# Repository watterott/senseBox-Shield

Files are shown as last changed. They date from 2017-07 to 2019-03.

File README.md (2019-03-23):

# senseBox-Shield
The senseBox-Shield is a plug-on module for Arduino to connect different sensor modules.

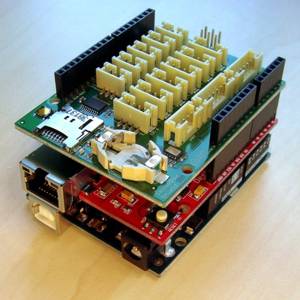
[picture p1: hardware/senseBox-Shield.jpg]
senseBox-Shield


* JST connectors for different sensors
* microSD socket (SPI) support SD and SDHC cards
* RV-8523 RTC (I2C Real-Time-Clock) with backup battery
* Open-Source
* **[Documentation on learn.watterott.com](https://learn.watterott.com)**

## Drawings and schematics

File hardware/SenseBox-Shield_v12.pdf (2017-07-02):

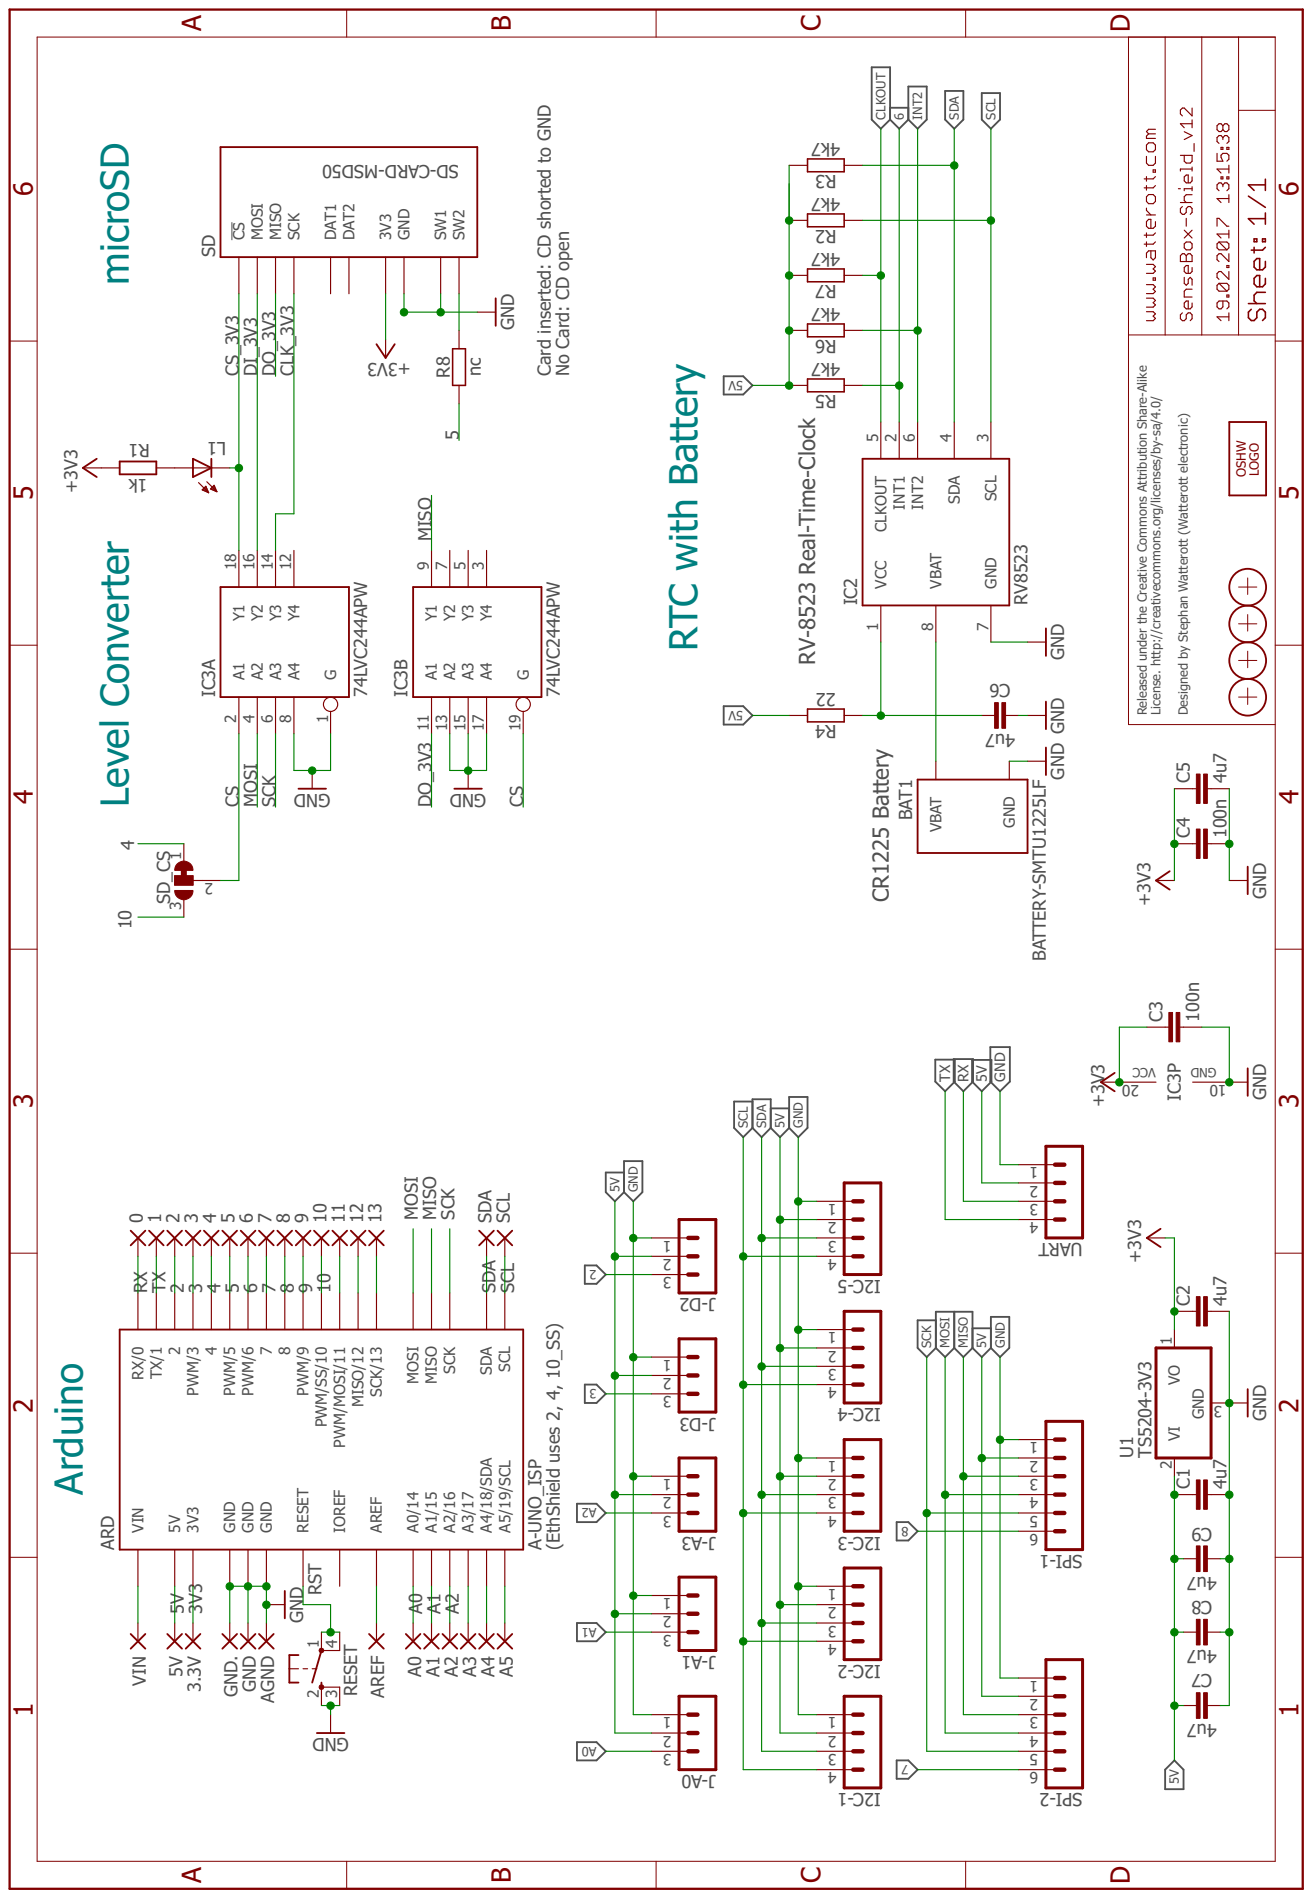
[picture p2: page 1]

Card inserted: CD shorted to GND

No Card: CD open

Released under the Creative Commons At ribution Share-Alike

License. http://creativecommons.org/licenses/by-sa/4.0/ Designed by Stephan Watterott (Watterott electronic)

RV-8523 Real-Time-Clock C

8 PWM/9 PWM/SS/10 PWM/MOSI/11 MISO/12 SCK/13 A1/15 A2/16 A3/17 A4/18/SDA

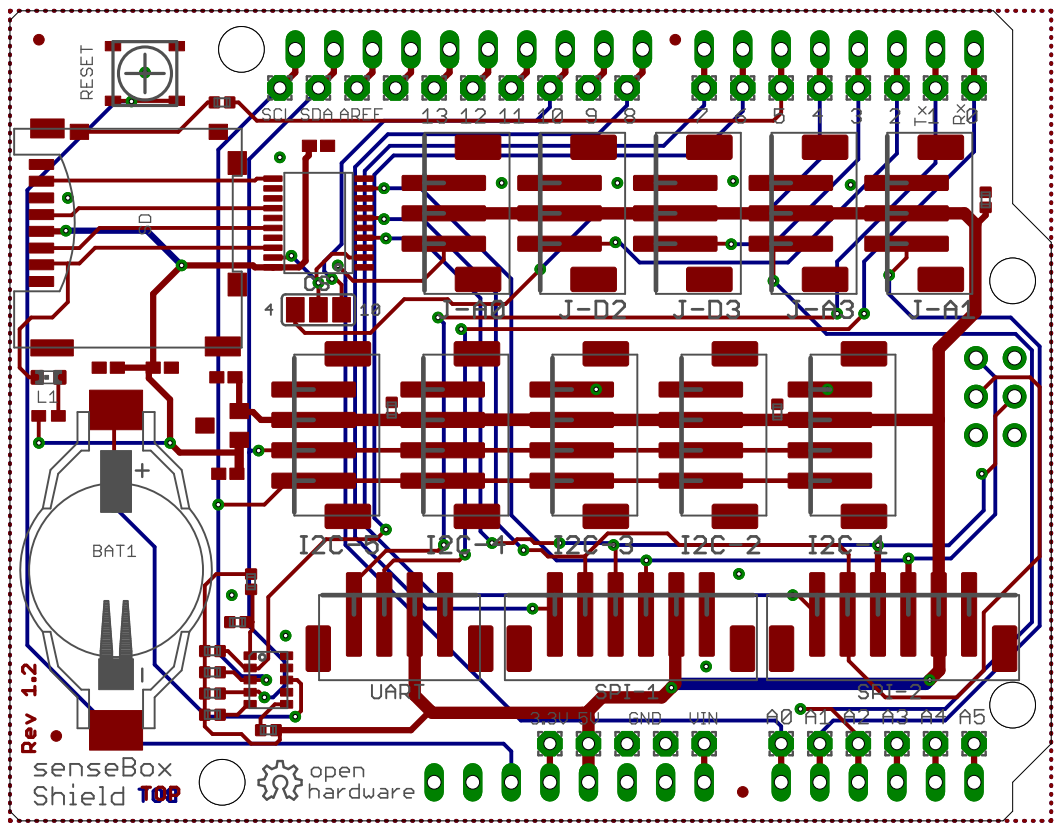
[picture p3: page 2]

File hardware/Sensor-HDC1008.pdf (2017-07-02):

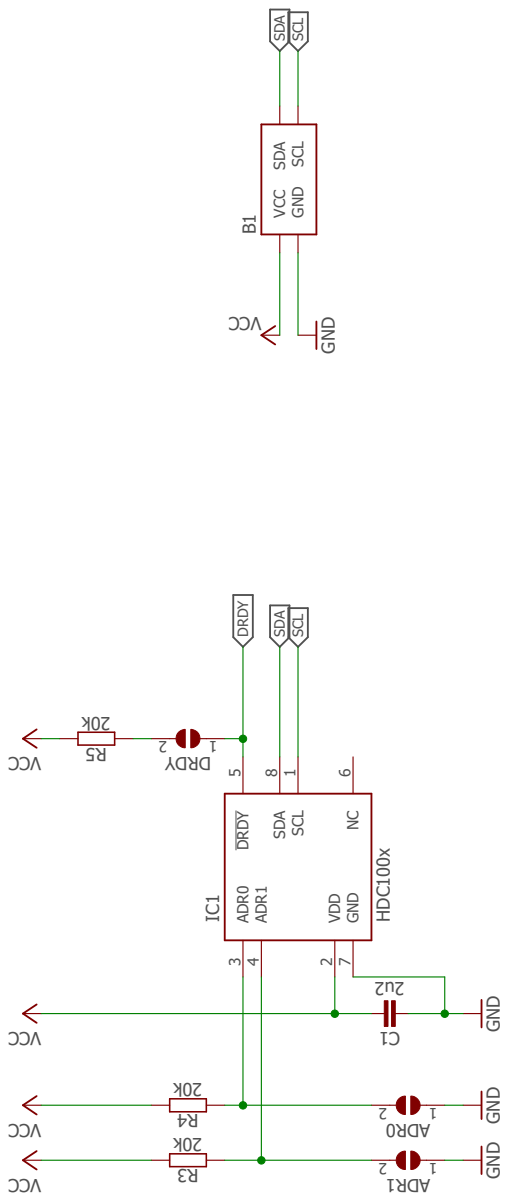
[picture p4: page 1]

CCV 2u2 GND k02 k02 CCV CCV k02 GND GND CCV GND CCV HDC100x Released under the Creative Commons At ribution Share-Alike License. http://creativecommons.org/licenses/by-sa/4.0/ Designed by Stephan Watterott (Watterott electronic) 1C 3R4R 5R 1RDA 2 1 0RDA 2 1 YDRD 2 1 SCL 1 VDD 2 ADR0 3 ADR1 4 SDA 8 GND 7 NC 6 DRDY 5 IC1 B1 SDA SCL VCC GND DRDY SDA SDA SCL SCL OSHW LOGO ABCD 1 2 3 4 5 6 ABCD 1 2 3 4 5 6

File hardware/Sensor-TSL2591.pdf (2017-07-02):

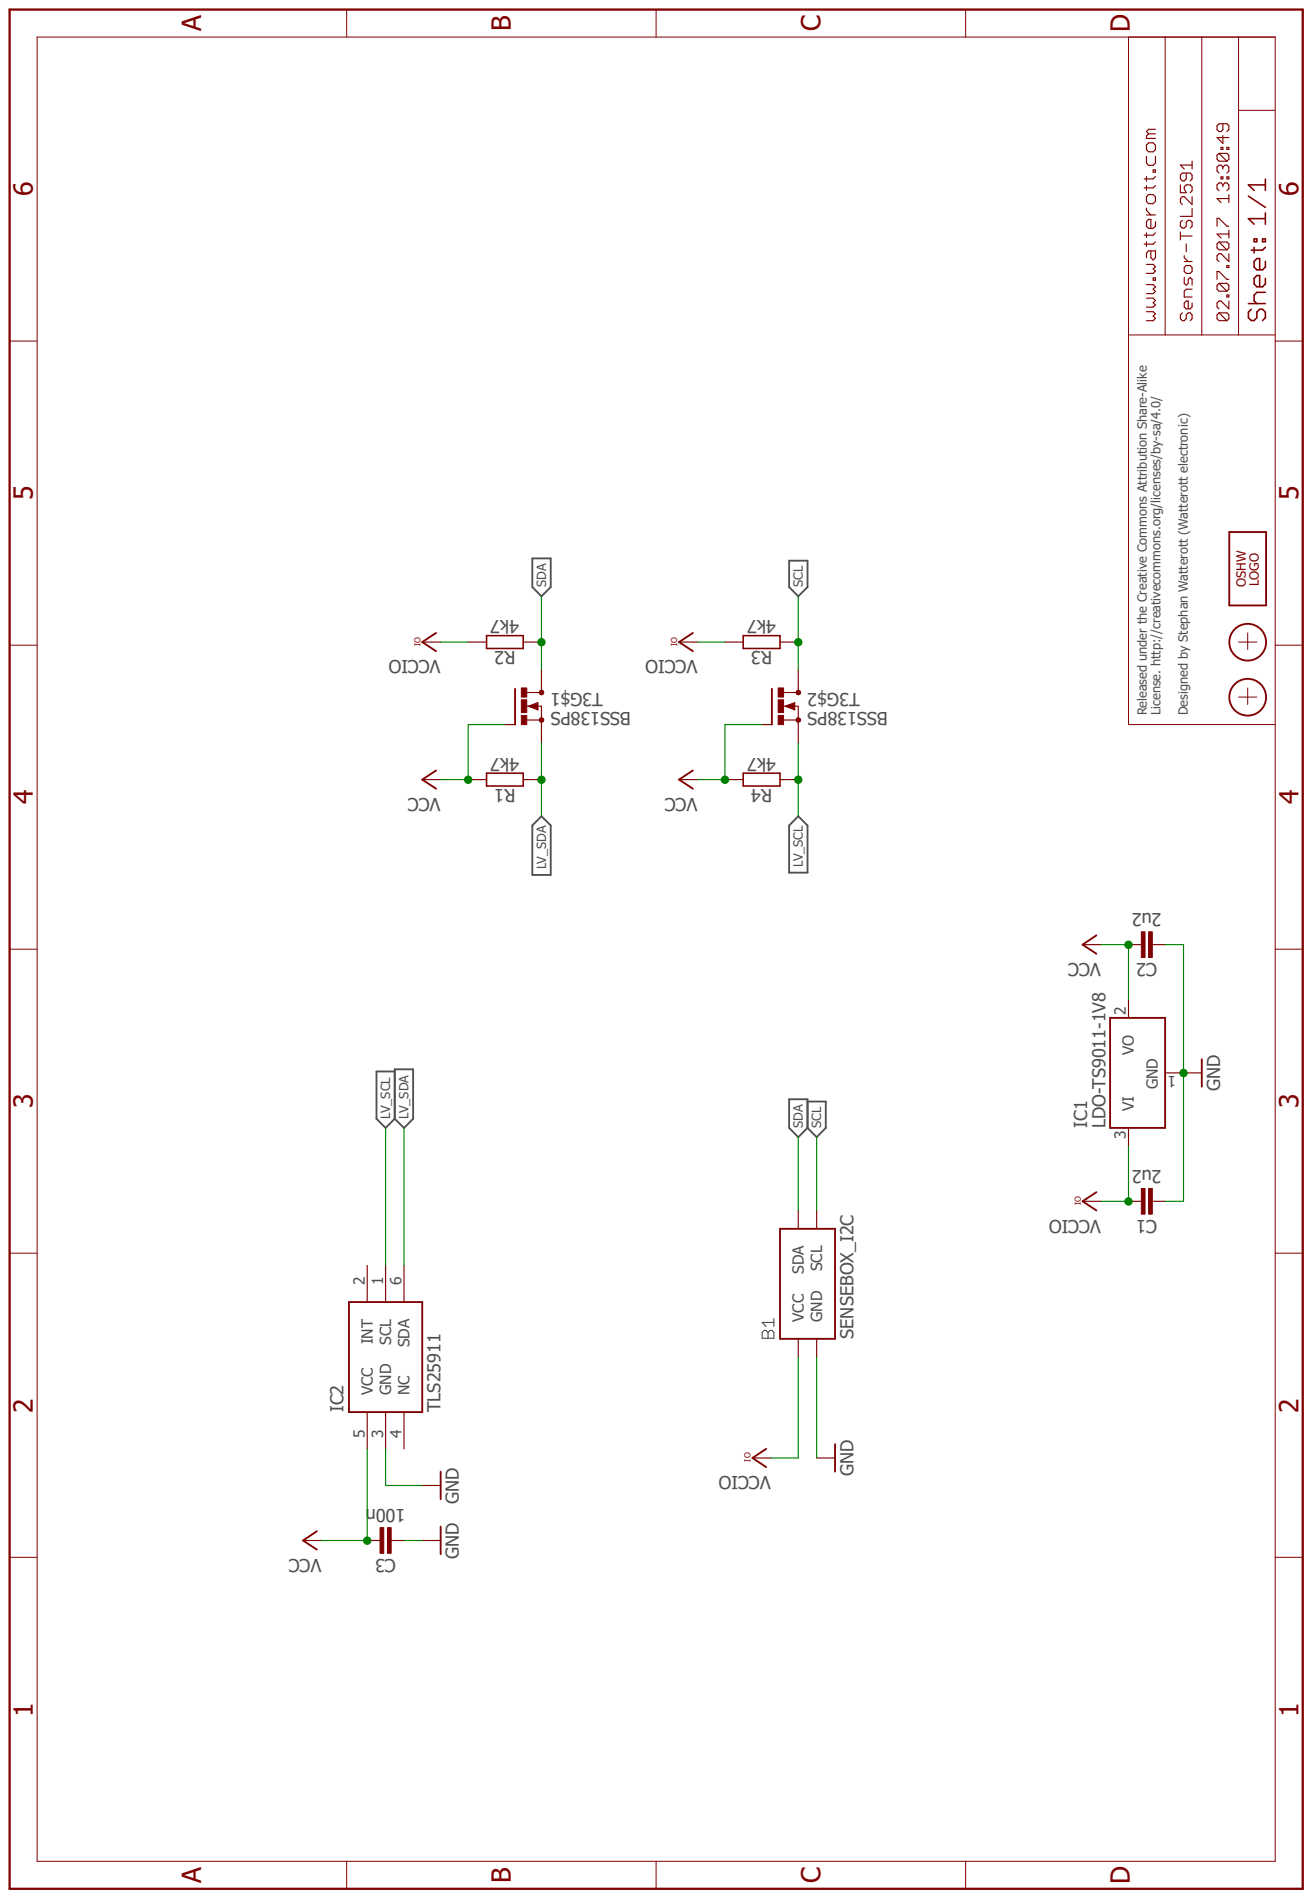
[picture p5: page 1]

GND CCV GND GND CCV LDO-TS9011-1V8 2u2 2u2 n001 7k4 7k4 OI CCV CCV 7k4 7k4 OI CCV OI CCV GND CCV OI CCV SP831SSB SP831SSB TLS25911 Released under the Creative Commons At ribution Share-Alike License. http://creativecommons.org/licenses/by-sa/4.0/ Designed by Stephan Watterott (Watterott electronic) IC1 GND VI 3 1 VO 2 1C2C 3C 2R1R 3R4R 1$G3T 2$G3T SCL 1 INT 2 GND 3 NC 4 VCC 5 SDA 6 IC2 SENSEBOX_I2C SDA SCL VCC GND SCL SCL SDA SDA LV_SDA LV_SDA LV_SCL LV_SCL OSHW LOGO IOIO IO IO ABCD 1 2 3 4 5 6 ABCD 1 2 3 4 5 6

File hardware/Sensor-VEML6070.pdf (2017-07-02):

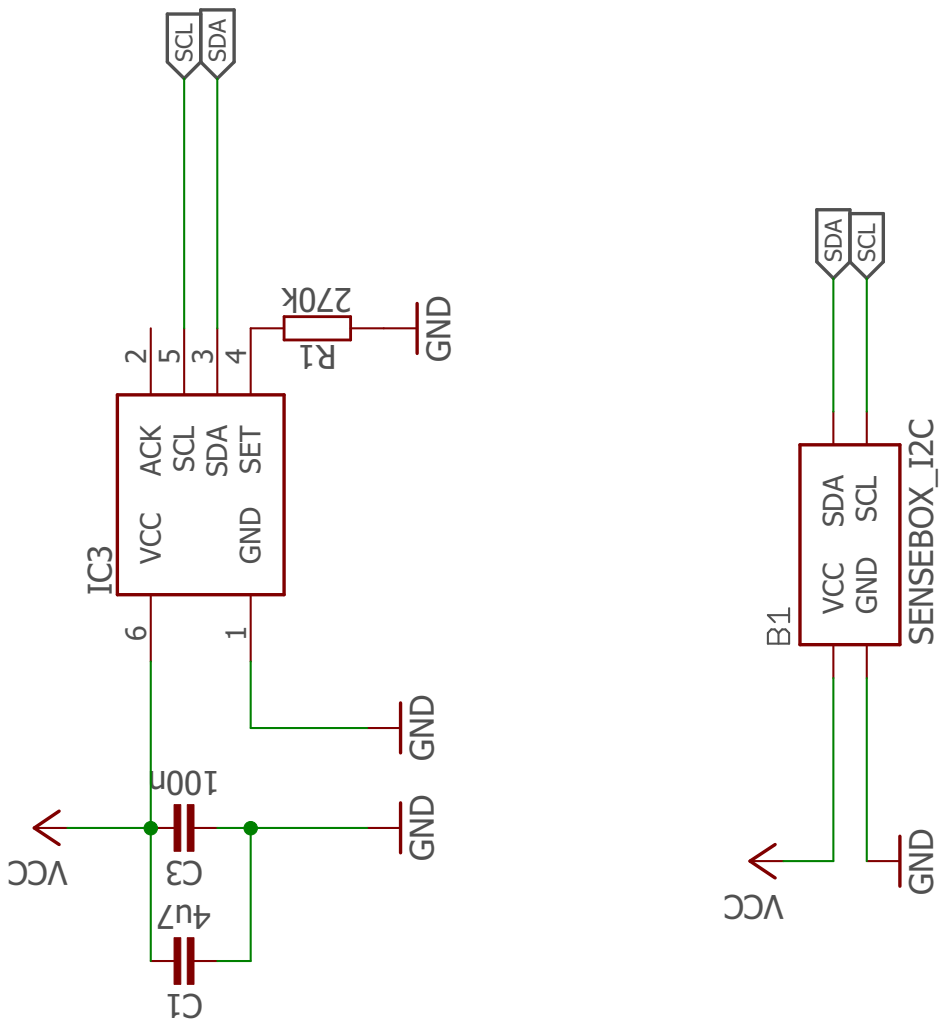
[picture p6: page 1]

GND GND GNCCV D n001 k072 CCV 7u4 GND Released under the Creative Commons At ribution Share-Alike License. http://creativecommons.org/licenses/by-sa/4.0/ Designed by Stephan Watterott (Watterott electronic) 3C 1R GND 1 ACK 2 SDA 3 SET 4 SCL 5 VCC 6 IC3 1C SENSEBOX_I2C SDA SCL VCC GND SCL SCL SDA SDA OSHW LOGO ABCD 1 2 3 4 5 6 ABCD 1 2 3 4 5 6

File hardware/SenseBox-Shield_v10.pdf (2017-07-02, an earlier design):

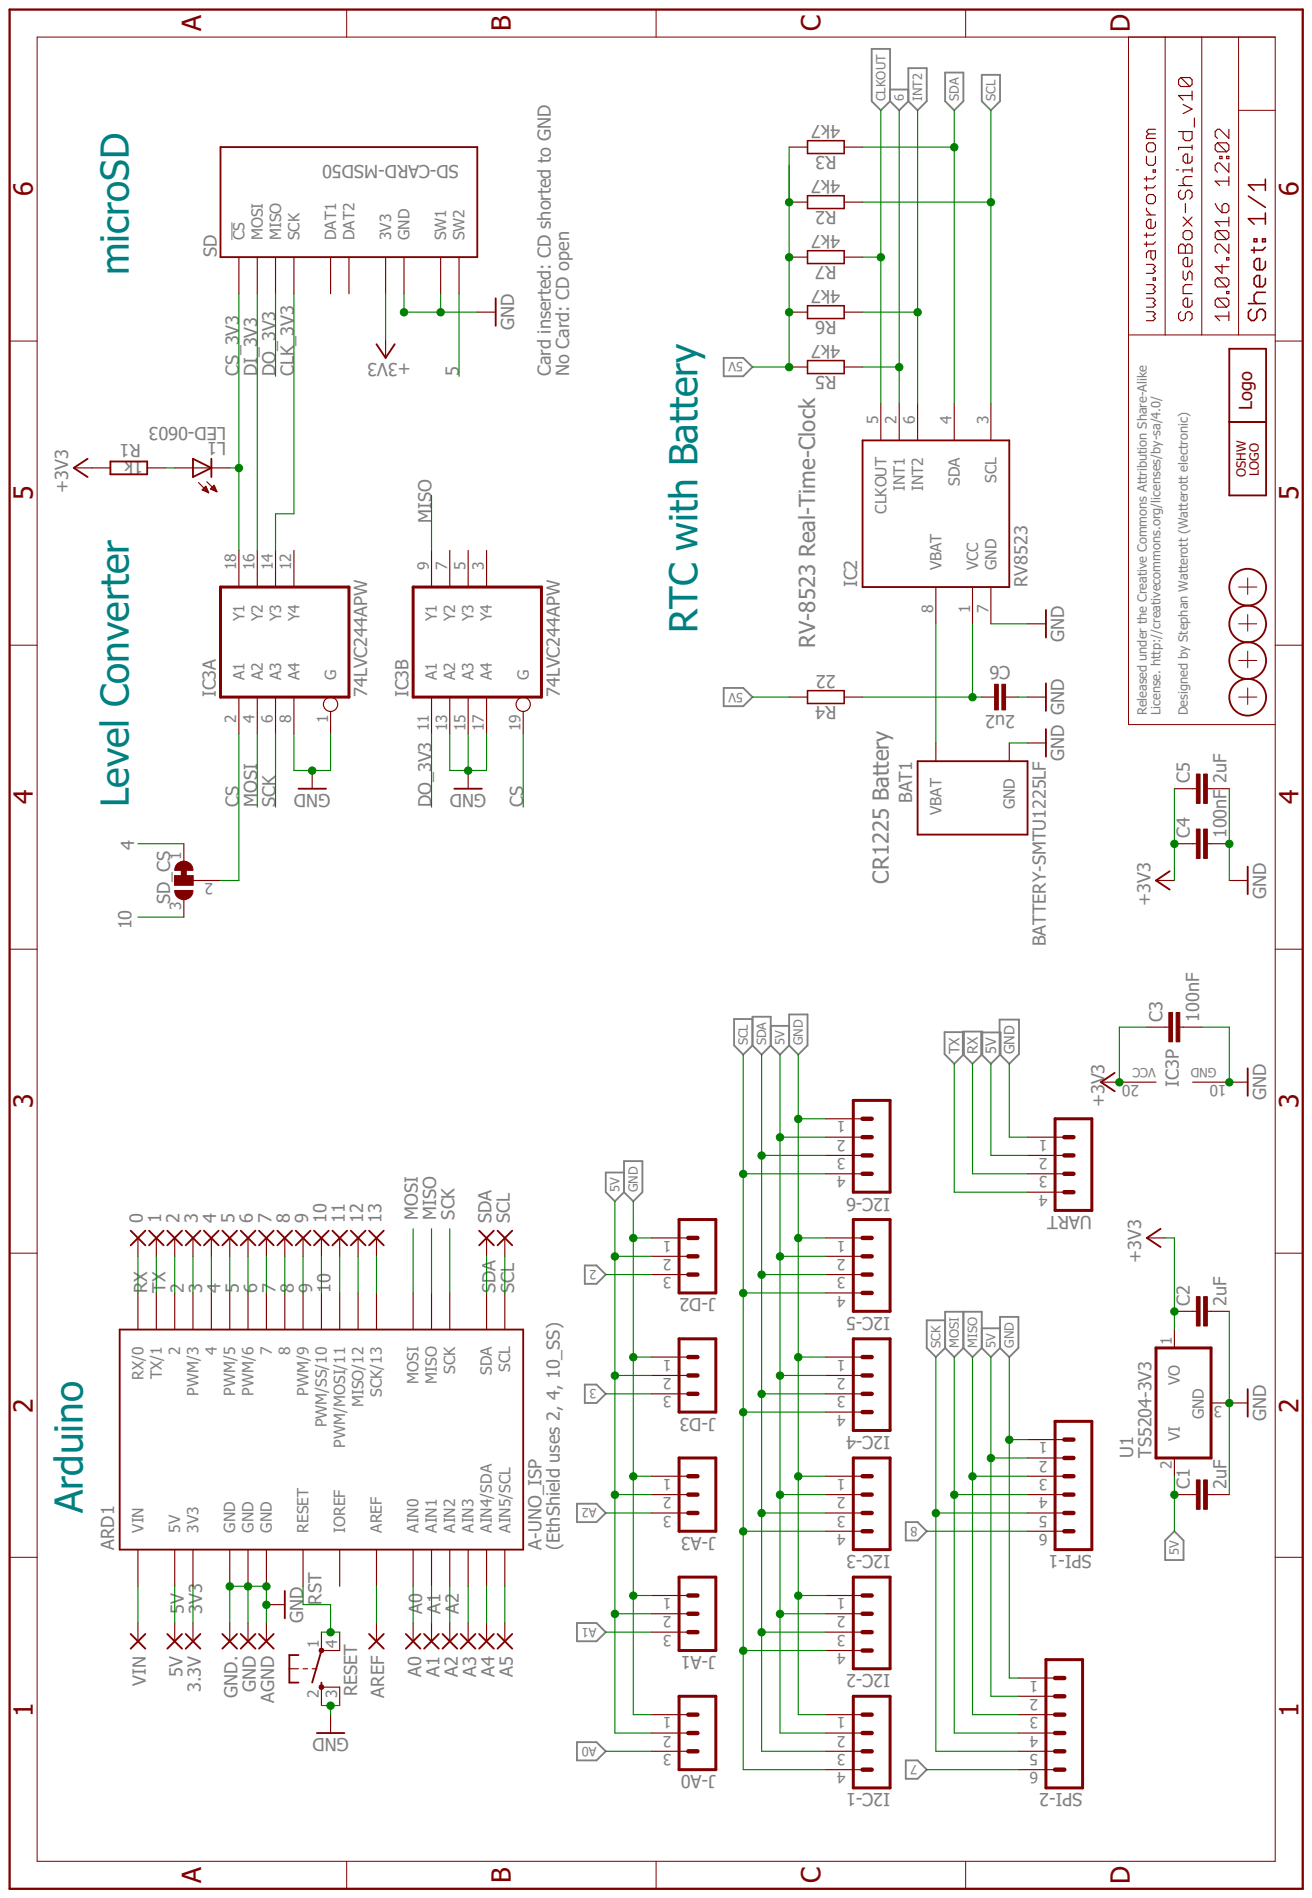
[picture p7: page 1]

Card inserted: CD shorted to GND

No Card: CD open

Released under the Creative Commons Attribution Share-Alike

License. http://creativecommons.org/licenses/by-sa/4.0/ Designed by Stephan Watterott (Watterott electronic)

RV-8523 Real-Time-Clock C

8 PWM/9 PWM/SS/10 PWM/MOSI/11 MISO/12 SCK/13 AIN1 AIN2 AIN3 AIN4/SDA

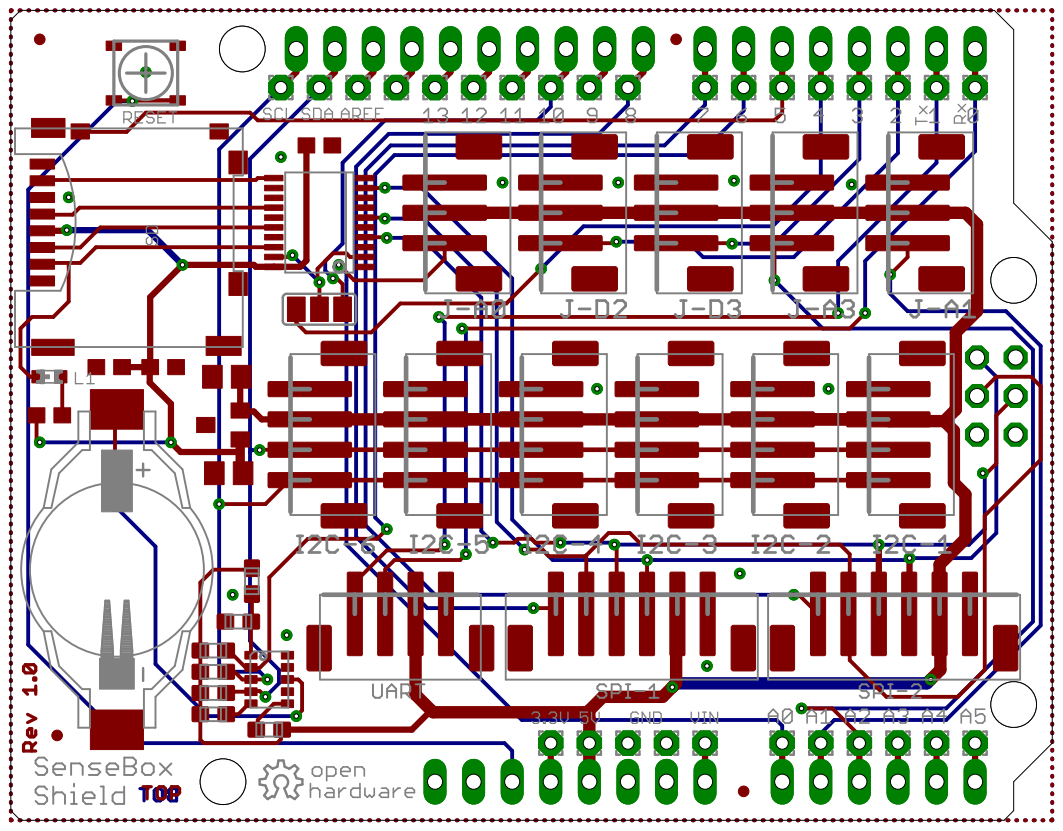
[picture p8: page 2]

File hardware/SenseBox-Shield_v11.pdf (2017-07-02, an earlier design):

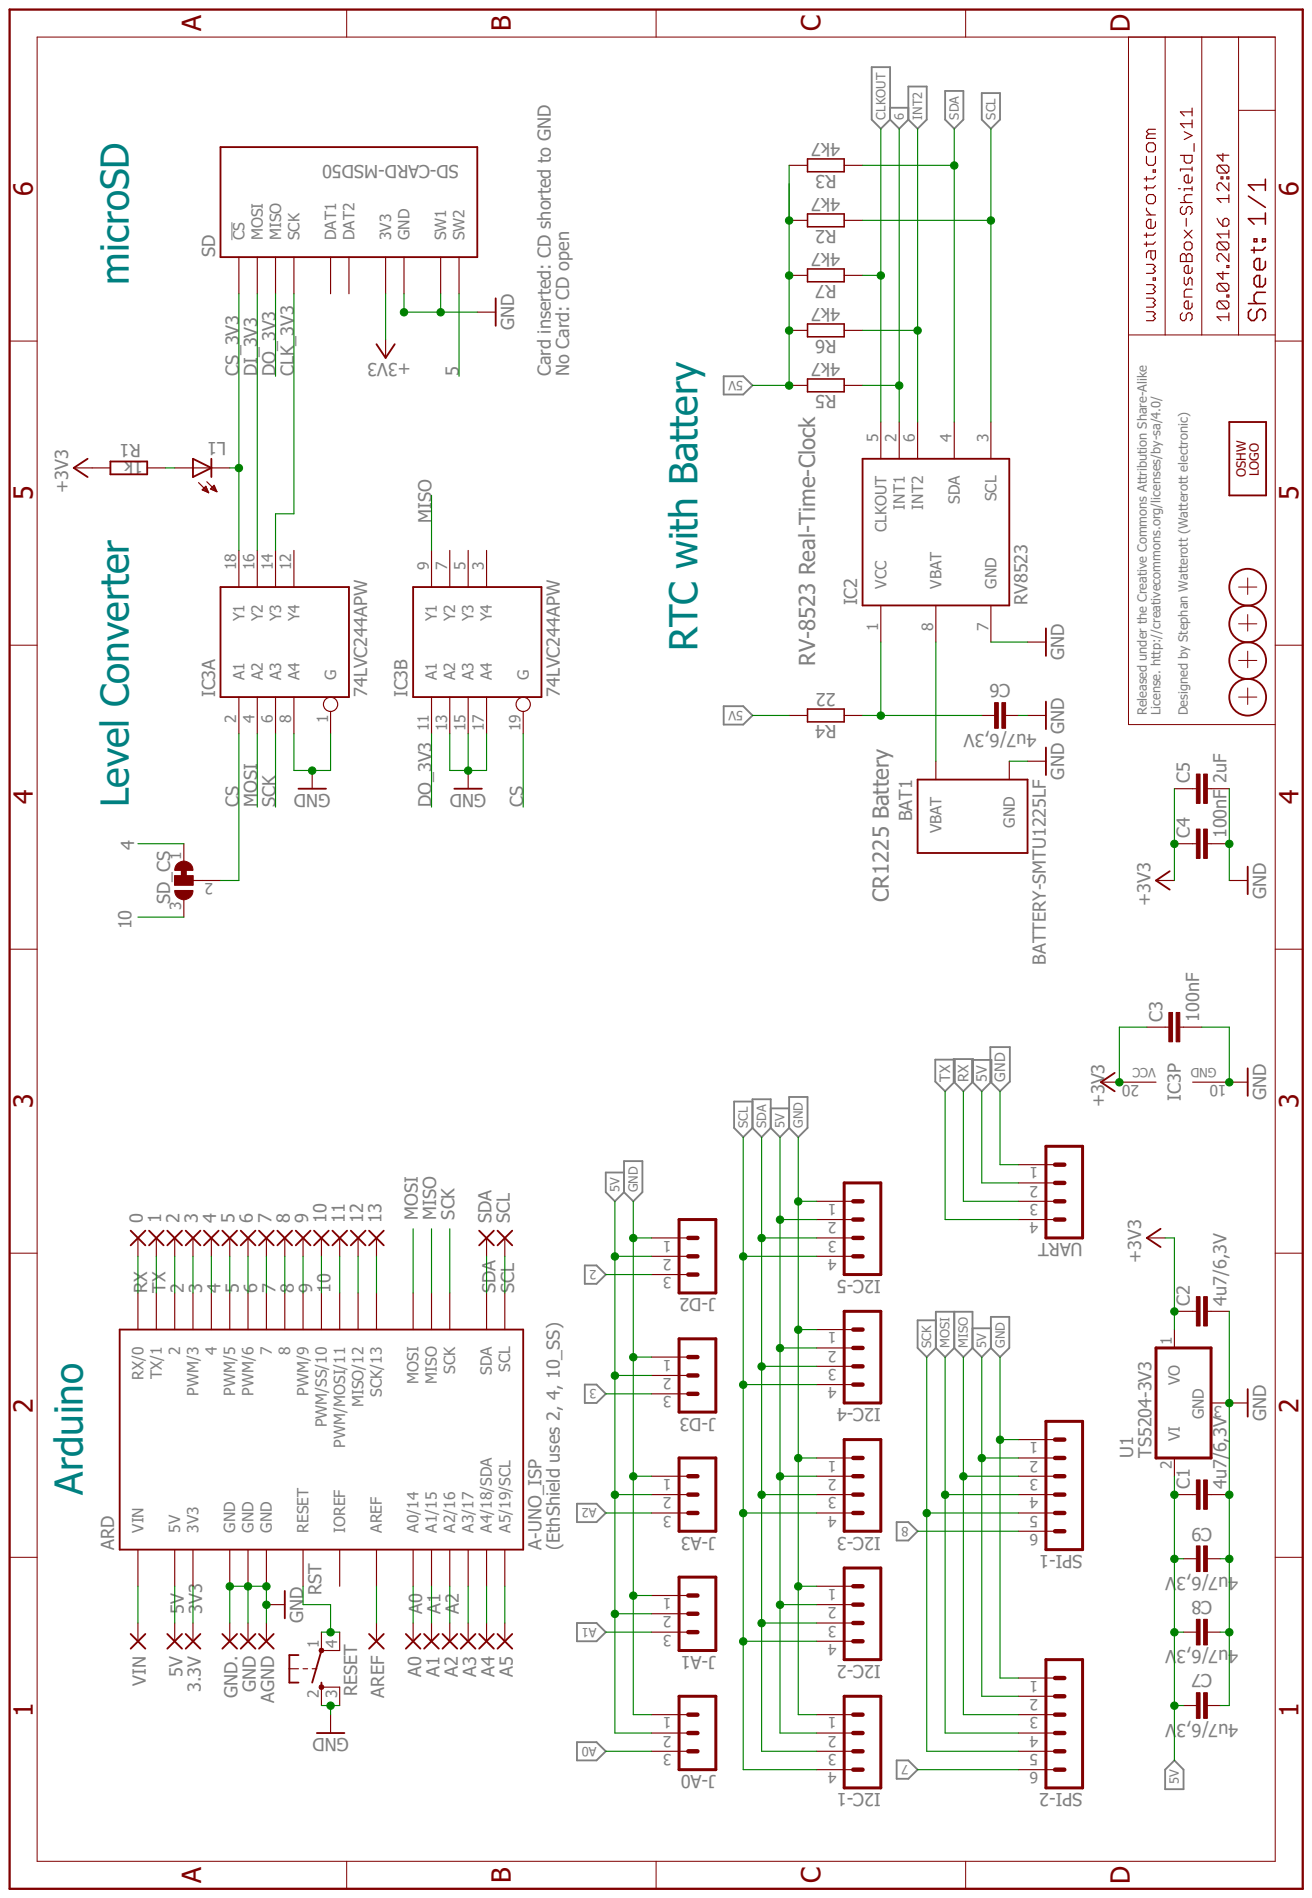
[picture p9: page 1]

Card inserted: CD shorted to GND

No Card: CD open

Released under the Creative Commons Attribution Share-Alike

License. http://creativecommons.org/licenses/by-sa/4.0/ Designed by Stephan Watterott (Watterott electronic)

RV-8523 Real-Time-Clock C

8 PWM/9 PWM/SS/10 PWM/MOSI/11 MISO/12 SCK/13 A1/15 A2/16 A3/17 A4/18/SDA

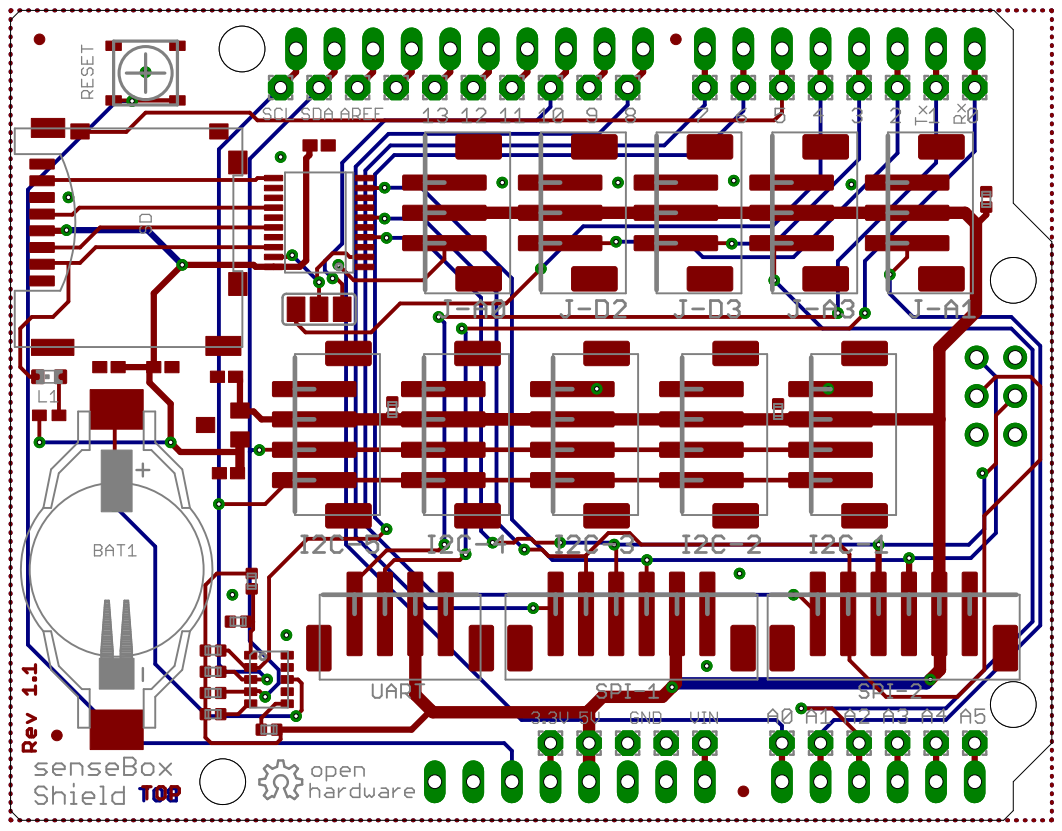
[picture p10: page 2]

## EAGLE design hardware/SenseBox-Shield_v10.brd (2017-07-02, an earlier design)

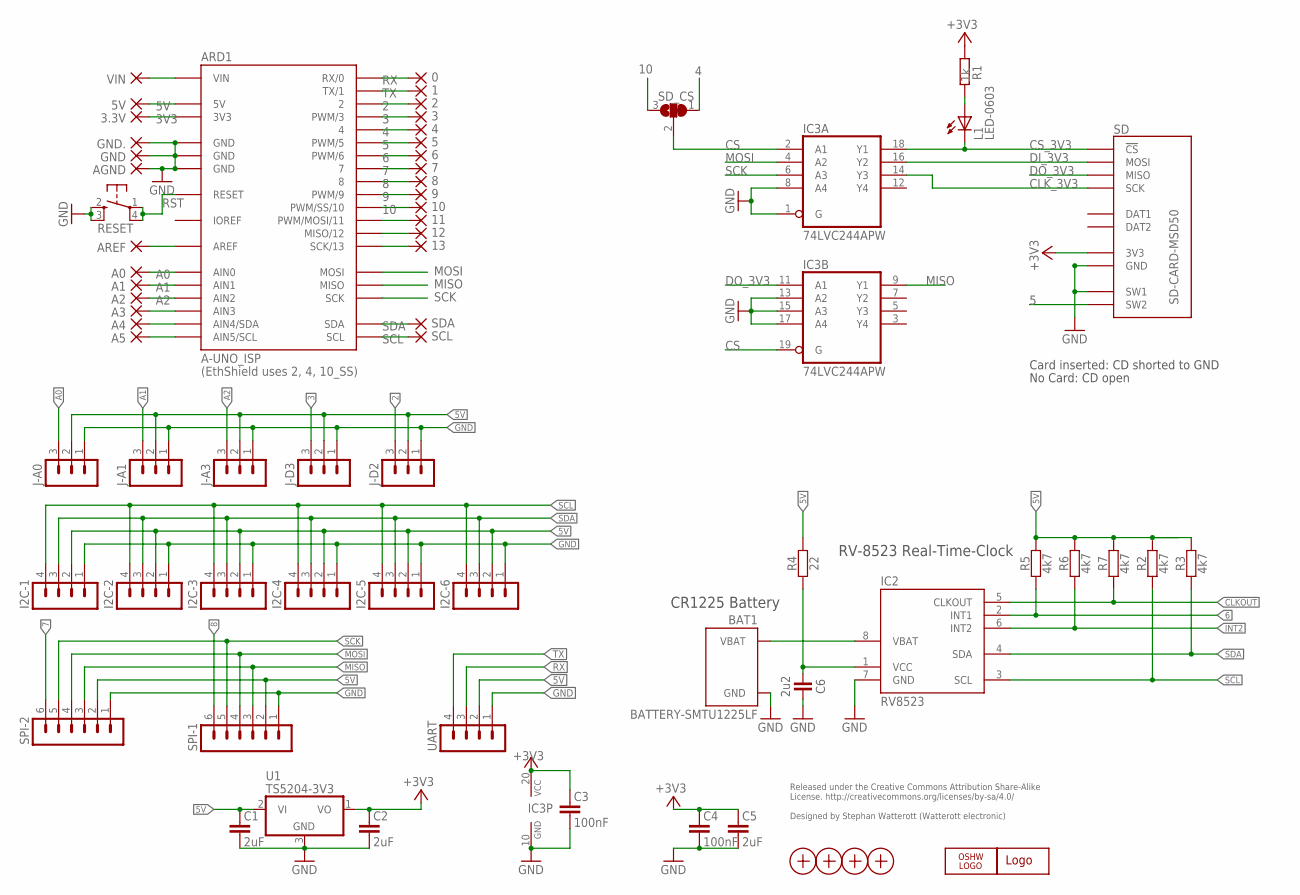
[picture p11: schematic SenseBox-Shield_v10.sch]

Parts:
0, 1, 2, 3, 3.3V, 4, 5, 5V, 6, 7, 8, 9, 10, 11, 12, 13: 1,6/0,8
A0, A1, A2, A3, A4, A5: 1,6/0,8
AGND: 1,6/0,8
ARD1: A-UNO_ISP; A-UNO-ISP
AREF: 1,6/0,8
BAT1: BATTERY-SMTU1225LF; BAT-SMTU1225LF
C1, C2: 2uF; C0805
C3, C4: 100nF; C0603
C5: 2uF; C0603
C6: 2u2; R0603
GND, GND.: 1,6/0,8
I2C-1, I2C-2, I2C-3, I2C-4, I2C-5, I2C-6: JST_PH_4B4B-PH-SM4-TB; JST_B4B-PH-SM4-TB
IC2: RV8523; RTC-C3
IC3: 74LVC244APW; TSSOP20
J-A0, J-A1, J-A3: JST_PH_3B3B-PH-SM4-TB; JST_B3B-PH-SM4-TB
J-D2, J-D3: JST_PH_3B3B-PH-SM4-TB; JST_B3B-PH-SM4-TB
L1: LED-0603; LED_0603
LOGO2: WE-LOGOPLACE; WE-LOGO
LOGO3: OSHW_LOGO_6MILX0100-NT; OSHW_6X100_NOTEXT
R1: 1k; R0603
R2, R3, R5, R6, R7: 4k7; R0603
R4: 22; R0603
RESET: SW4S; SW_SMD4
SCL: 1,6/0,8
SD: SD-CARD-MSD50; SD_5031821853
SDA: 1,6/0,8
SD_CS: SJ2W; SJ_2
SPI-1, SPI-2: JST_PH_6B6B-PH-SM4-TB; JST_B6B-PH-SM4-TB
U1: TS5204-3V3; SOT23
UART: JST_PH_4B4B-PH-SM4-TB; JST_B4B-PH-SM4-TB
VIN: 1,6/0,8
X1, X2, X3, X4: PASSER

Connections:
2: 2.1, ARD1.2, J-D2.3
3: 3.1, ARD1.3 (PWM/3), J-D3.3
3V3: 3.3V.1, ARD1.3V3
4: 4.1, ARD1.4, SD_CS.1
5: 5.1, ARD1.5 (PWM/5), SD.SW2
5V: 5V.1, ARD1.5V, C1.1, I2C-1.2, I2C-2.2, I2C-3.2, I2C-4.2, I2C-5.2, I2C-6.2, J-A0.2, J-A1.2, J-A3.2, J-D2.2, J-D3.2, R2.2, R3.2, R4.2, R5.2, R6.2, R7.2, SPI-1.2, SPI-2.2, U1.2 (VI), UART.2
6: 6.1, ARD1.6 (PWM/6), IC2.2 (INT1), R5.1
7: 7.1, ARD1.7, SPI-2.6
8: 8.1, ARD1.8, SPI-1.6
9: 9.1, ARD1.9 (PWM/9)
10: 10.1, ARD1.10 (PWM/SS/10), SD_CS.3
11: 11.1, ARD1.11 (PWM/MOSI/11)
12: 12.1, ARD1.12 (MISO/12)
13: 13.1, ARD1.13 (SCK/13)
+3V3: C2.1, C3.1, C4.1, C5.1, IC3.20 (VCC), R1.1, SD.VCC (3V3), U1.1 (VO)
A0: A0.1, ARD1.A0 (AIN0), J-A0.3
A1: A1.1, ARD1.A1 (AIN1), J-A1.3
A2: A2.1, ARD1.A2 (AIN2), J-A3.3
AIN3: A3.1, ARD1.A3 (AIN3)
AIN4: A4.1, ARD1.A4 (AIN4/SDA)
AIN5: A5.1, ARD1.A5 (AIN5/SCL)
AREF: ARD1.AREF, AREF.1
CLKOUT: IC2.5 (CLKOUT), R7.1
CLK_3V3: IC3.14 (Y3), SD.SCK
CS: IC3.2 (A1), IC3.19 (G), SD_CS.2
CS_3V3: IC3.18 (Y1), L1.C, SD.CS (!CS)
DI_3V3: IC3.16 (Y2), SD.MOSI
DO_3V3: IC3.11 (A1), SD.MISO
GND: AGND.1, ARD1.GND@1 (GND), ARD1.GND@2 (GND), ARD1.GND@3 (GND), BAT1.- (GND), C1.2, C2.2, C3.2, C4.2, C5.2, C6.2, GND.1, GND..1, I2C-1.1, I2C-2.1, I2C-3.1, I2C-4.1, I2C-5.1, I2C-6.1, IC2.7 (GND), IC3.1 (G), IC3.8 (A4), IC3.10 (GND), IC3.13 (A2), IC3.15 (A3), IC3.17 (A4), J-A0.1, J-A1.1, J-A3.1, J-D2.1, J-D3.1, RESET.2 (S), RESET.3 (S1), SD.GND, SD.SW1, SPI-1.1, SPI-2.1, U1.3 (GND), UART.1
INT2: IC2.6 (INT2), R6.1
IOREF: ARD1.IOREF
MISO: ARD1.MISO, IC3.9 (Y1), SPI-1.3, SPI-2.3
MOSI: ARD1.MOSI, IC3.4 (A2), SPI-1.4, SPI-2.4
unnamed: L1.A, R1.2
RST: ARD1.RST (RESET), RESET.1, RESET.4 (P1)
RV_VCC: C6.1, IC2.1 (VCC), R4.1
RX: 0.1, ARD1.0 (RX/0), UART.3
SCK: ARD1.SCK, IC3.6 (A3), SPI-1.5, SPI-2.5
SCL: ARD1.SCL, I2C-1.4, I2C-2.4, I2C-3.4, I2C-4.4, I2C-5.4, I2C-6.4, IC2.3 (SCL), R2.1, SCL.1
SDA: ARD1.SDA, I2C-1.3, I2C-2.3, I2C-3.3, I2C-4.3, I2C-5.3, I2C-6.3, IC2.4 (SDA), R3.1, SDA.1
TX: 1.1, ARD1.1 (TX/1), UART.4
VBAT: BAT1.+ (VBAT), IC2.8 (VBAT)
VIN: ARD1.VIN, VIN.1

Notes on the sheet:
Released under the Creative Commons Attribution Share-Alike License. http://creativecommons.org/licenses/by-sa/4.0/ Designed by Stephan Watterott (Watterott electronic)
(EthShield uses 2, 4, 10_SS)
Card inserted: CD shorted to GND
No Card: CD open
RV-8523 Real-Time-Clock
CR1225 Battery

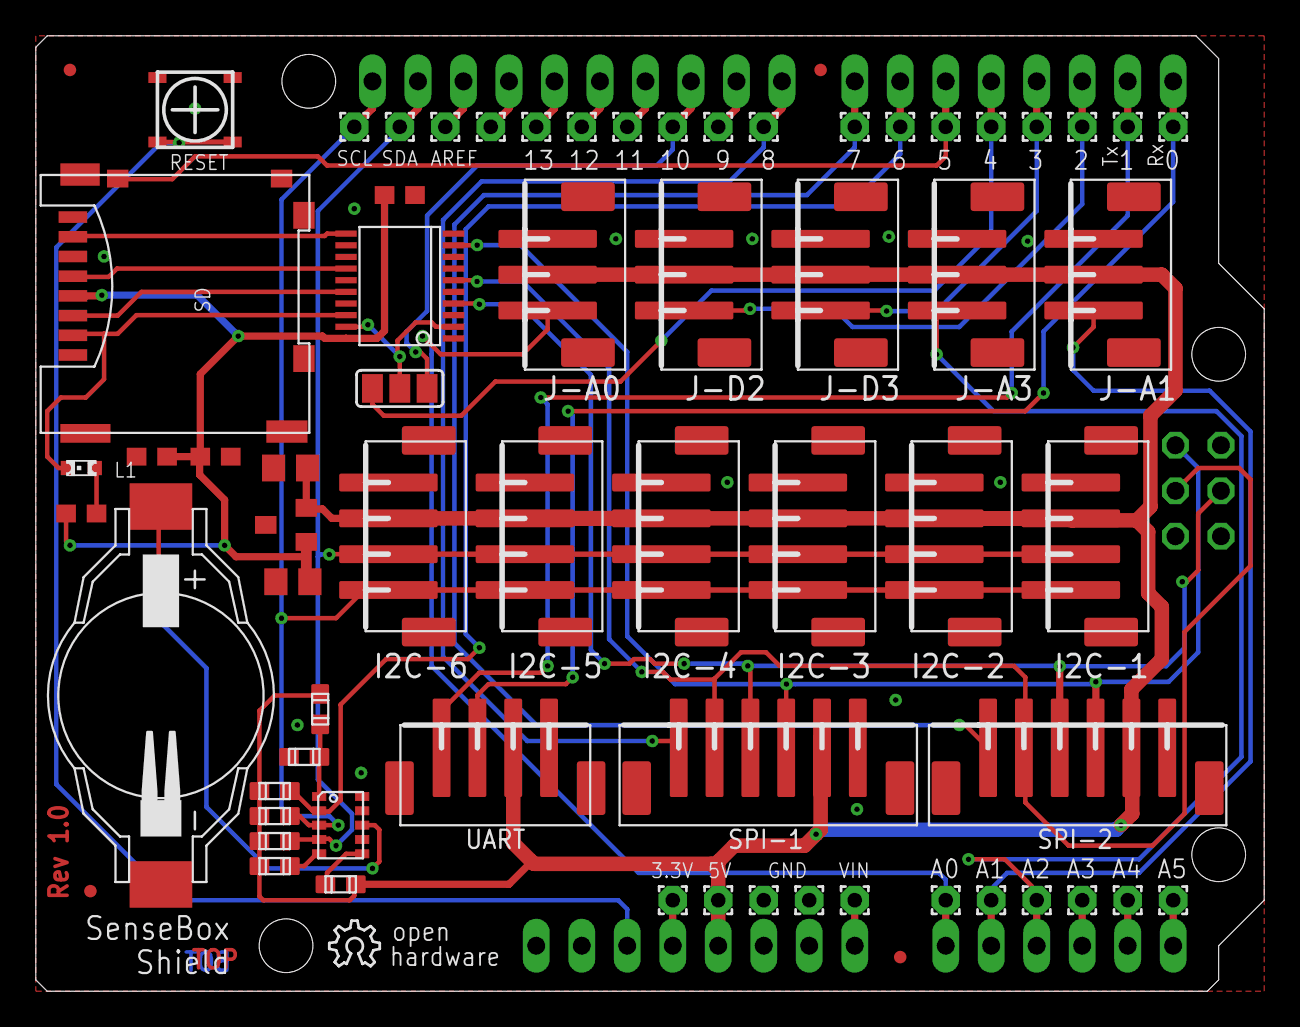
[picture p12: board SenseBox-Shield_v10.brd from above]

Board: 2 copper layers, 68.6 x 53.3 mm, 71 parts (1 on the bottom side), 42 nets.

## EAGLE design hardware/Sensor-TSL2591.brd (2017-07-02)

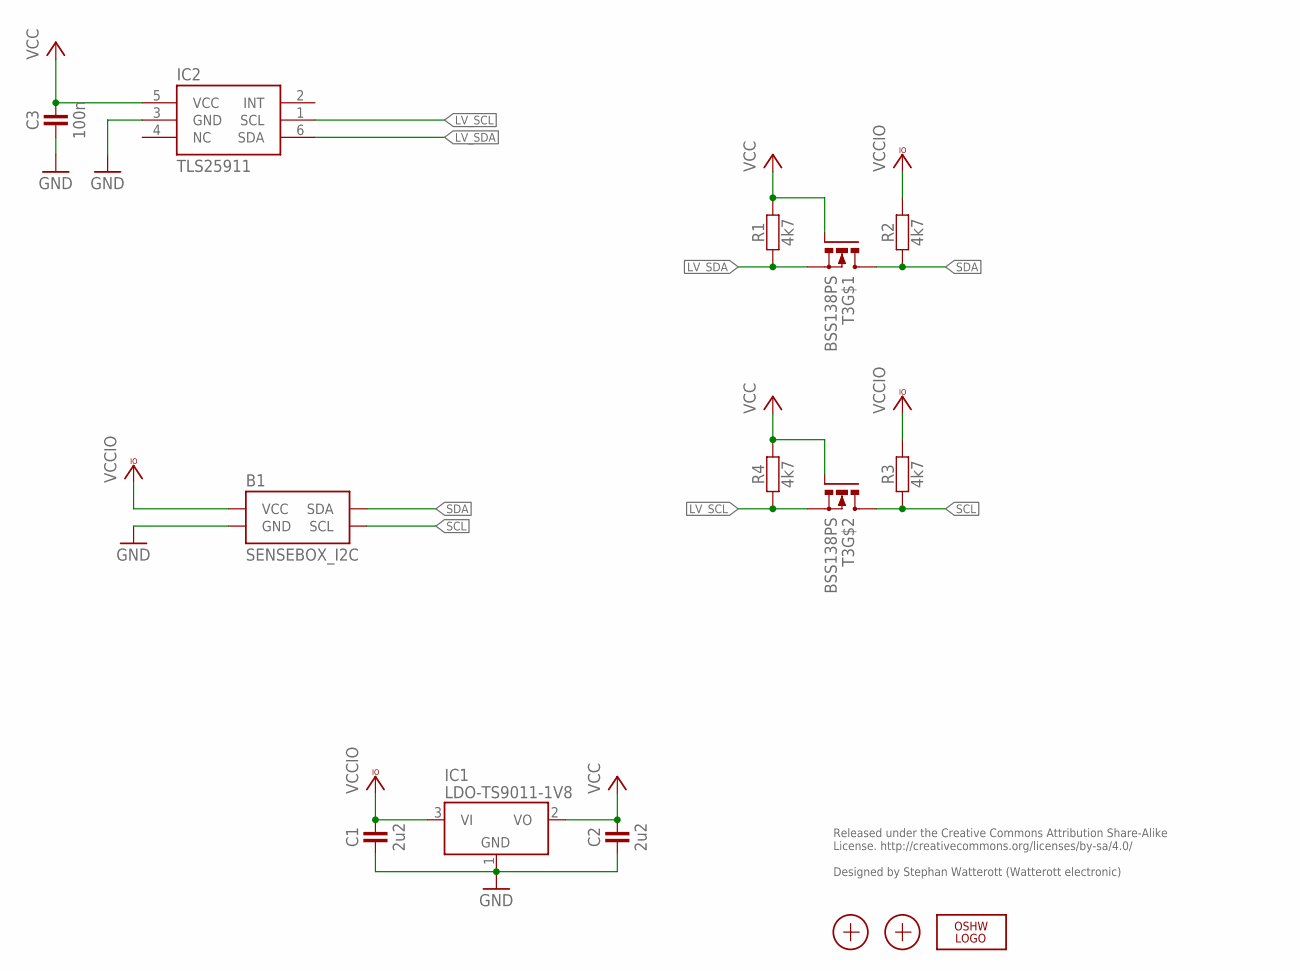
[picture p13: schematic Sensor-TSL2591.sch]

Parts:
B1: SENSEBOX_I2C; BREAKOUT_SENSEBOX_I2C
C1, C2: 2u2; R0402
C3: 100n; R0402
IC1: LDO-TS9011-1V8; SOT23
IC2: TLS25911; WFDFN6
LOGO2: OSHW_LOGOX0070; OSHW_6X70
R1, R2, R3, R4: 4k7; R0402
T3: BSS138PS; SOT363
X1, X2: PASSER-07; PASSER_07MM

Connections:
GND: B1.GND, C1.1, C2.1, C3.1, IC1.1 (GND), IC2.3 (GND)
LV_SCL: IC2.1 (SCL), R4.1, T3.4 (S)
LV_SDA: IC2.6 (SDA), R1.1, T3.1 (S)
SCL: B1.SCL, R3.1, T3.3 (D)
SDA: B1.SDA, R2.1, T3.6 (D)
VCC: C2.2, C3.2, IC1.2 (VO), IC2.5 (VCC), R1.2, R4.2, T3.2 (G), T3.5 (G)
VCCIO: B1.VCC, C1.2, IC1.3 (VI), R2.2, R3.2

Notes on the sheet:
Released under the Creative Commons Attribution Share-Alike License. http://creativecommons.org/licenses/by-sa/4.0/ Designed by Stephan Watterott (Watterott electronic)

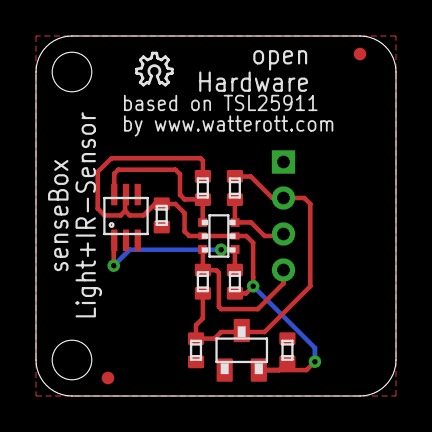
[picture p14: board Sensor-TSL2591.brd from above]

Board: 2 copper layers, 20.0 x 20.0 mm, 14 parts (0 on the bottom side), 7 nets.

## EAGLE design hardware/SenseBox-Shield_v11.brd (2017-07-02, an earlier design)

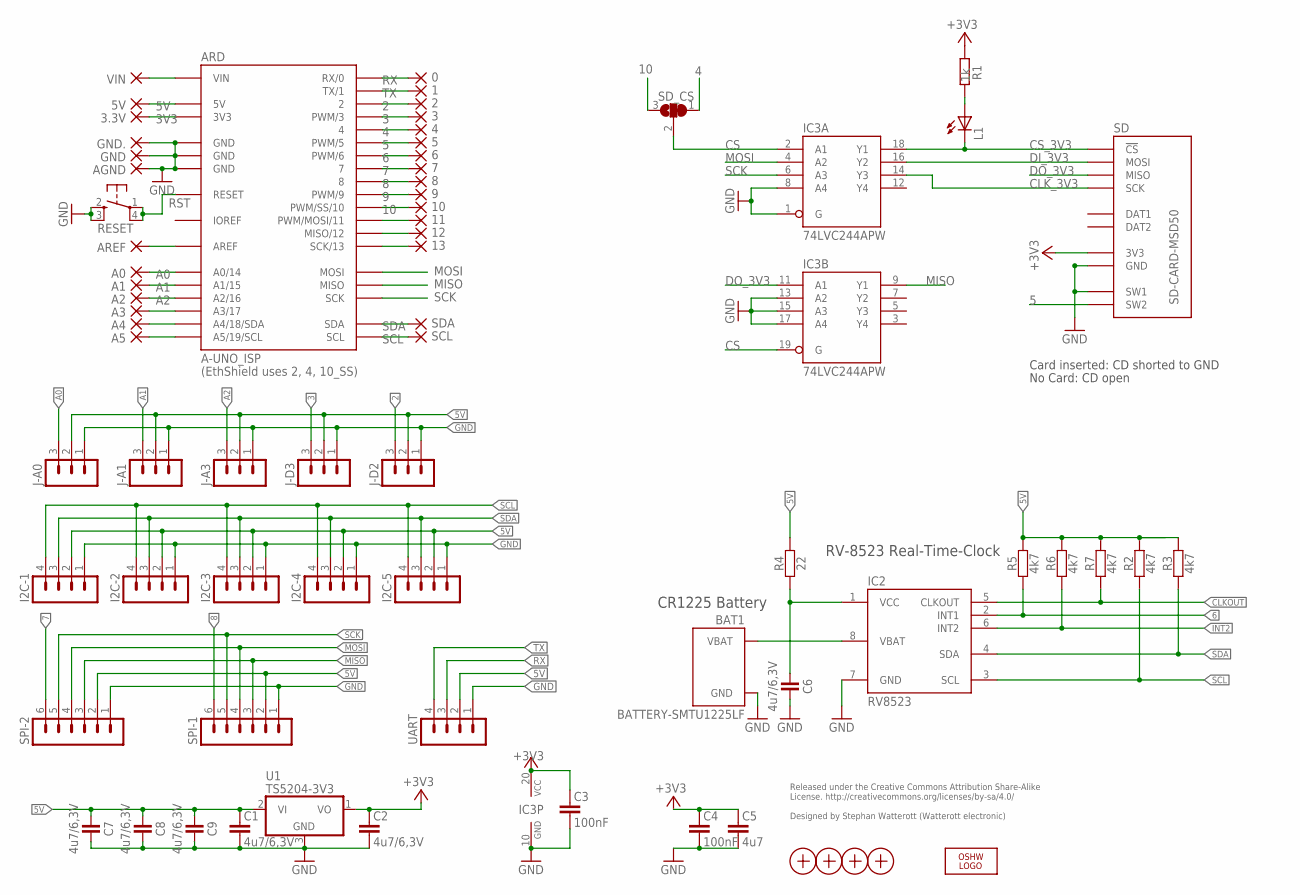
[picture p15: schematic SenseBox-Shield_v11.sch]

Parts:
0, 1, 2, 3, 3.3V, 4, 5, 5V, 6, 7, 8, 9, 10, 11, 12, 13: 1,6/0,8
A0, A1, A2, A3, A4, A5: 1,6/0,8
AGND: 1,6/0,8
ARD: A-UNO_ISP; A-UNO-ISP
AREF: 1,6/0,8
BAT1: BATTERY-SMTU1225LF; BAT-SMTU1225LF
C1, C2: 4u7/6,3V; C0402K
C3, C4: 100nF; C0402K
C5: 4u7; C0402K
C6, C7, C8, C9: 4u7/6,3V; C0402
GND, GND.: 1,6/0,8
I2C-1, I2C-2, I2C-3, I2C-4, I2C-5: JST_PH_4B4B-PH-SM4-TB; JST_B4B-PH-SM4-TB
IC2: RV8523; RTC-C3
IC3: 74LVC244APW; TSSOP20
J-A0, J-A1, J-A3: JST_PH_3B3B-PH-SM4-TB; JST_B3B-PH-SM4-TB
J-D2, J-D3: JST_PH_3B3B-PH-SM4-TB; JST_B3B-PH-SM4-TB
L1: LED-0603; C0603
LOGO3: OSHW_LOGO_6MILX0100-NT; OSHW_6X100_NOTEXT
R1: 1k; R0402
R2, R3, R5, R6, R7: 4k7; C0402
R4: 22; C0402
RESET: SW4S; SW_SMD4
SCL: 1,6/0,8
SD: SD-CARD-MSD50; SD_5031821853
SDA: 1,6/0,8
SD_CS: SJ2W; SJ_2
SPI-1, SPI-2: JST_PH_6B6B-PH-SM4-TB; JST_B6B-PH-SM4-TB
U1: TS5204-3V3; SOT23
UART: JST_PH_4B4B-PH-SM4-TB; JST_B4B-PH-SM4-TB
VIN: 1,6/0,8
X1, X2, X3, X4: PASSER

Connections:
2: 2.1, ARD.2, J-D2.3
3: 3.1, ARD.3 (PWM/3), J-D3.3
3V3: 3.3V.1, ARD.3V3
4: 4.1, ARD.4, SD_CS.1
5: 5.1, ARD.5 (PWM/5), SD.SW2
5V: 5V.1, ARD.5V, C1.1, C7.1, C8.1, C9.1, I2C-1.2, I2C-2.2, I2C-3.2, I2C-4.2, I2C-5.2, J-A0.2, J-A1.2, J-A3.2, J-D2.2, J-D3.2, R2.2, R3.2, R4.2, R5.2, R6.2, R7.2, SPI-1.2, SPI-2.2, U1.2 (VI), UART.2
6: 6.1, ARD.6 (PWM/6), IC2.2 (INT1), R5.1
7: 7.1, ARD.7, SPI-2.6
8: 8.1, ARD.8, SPI-1.6
9: 9.1, ARD.9 (PWM/9)
10: 10.1, ARD.10 (PWM/SS/10), SD_CS.3
11: 11.1, ARD.11 (PWM/MOSI/11)
12: 12.1, ARD.12 (MISO/12)
13: 13.1, ARD.13 (SCK/13)
+3V3: C2.1, C3.1, C4.1, C5.1, IC3.20 (VCC), R1.1, SD.VCC (3V3), U1.1 (VO)
A0: A0.1, ARD.A0 (A0/14), J-A0.3
A1: A1.1, ARD.A1 (A1/15), J-A1.3
A2: A2.1, ARD.A2 (A2/16), J-A3.3
AIN3: A3.1, ARD.A3 (A3/17)
AIN4: A4.1, ARD.A4 (A4/18/SDA)
AIN5: A5.1, ARD.A5 (A5/19/SCL)
AREF: ARD.AREF, AREF.1
CLKOUT: IC2.5 (CLKOUT), R7.1
CLK_3V3: IC3.14 (Y3), SD.SCK
CS: IC3.2 (A1), IC3.19 (G), SD_CS.2
CS_3V3: IC3.18 (Y1), L1.C, SD.CS (!CS)
DI_3V3: IC3.16 (Y2), SD.MOSI
DO_3V3: IC3.11 (A1), SD.MISO
GND: AGND.1, ARD.GND@1 (GND), ARD.GND@2 (GND), ARD.GND@3 (GND), BAT1.- (GND), C1.2, C2.2, C3.2, C4.2, C5.2, C6.2, C7.2, C8.2, C9.2, GND.1, GND..1, I2C-1.1, I2C-2.1, I2C-3.1, I2C-4.1, I2C-5.1, IC2.7 (GND), IC3.1 (G), IC3.8 (A4), IC3.10 (GND), IC3.13 (A2), IC3.15 (A3), IC3.17 (A4), J-A0.1, J-A1.1, J-A3.1, J-D2.1, J-D3.1, RESET.2 (S), RESET.3 (S1), SD.GND, SD.SW1, SPI-1.1, SPI-2.1, U1.3 (GND), UART.1
INT2: IC2.6 (INT2), R6.1
IOREF: ARD.IOREF
MISO: ARD.MISO, IC3.9 (Y1), SPI-1.3, SPI-2.3
MOSI: ARD.MOSI, IC3.4 (A2), SPI-1.4, SPI-2.4
unnamed: L1.A, R1.2
RST: ARD.RST@1 (RESET), RESET.1, RESET.4 (P1)
RV_VCC: C6.1, IC2.1 (VCC), R4.1
RX: 0.1, ARD.0 (RX/0), UART.3
SCK: ARD.SCK, IC3.6 (A3), SPI-1.5, SPI-2.5
SCL: ARD.SCL, I2C-1.4, I2C-2.4, I2C-3.4, I2C-4.4, I2C-5.4, IC2.3 (SCL), R2.1, SCL.1
SDA: ARD.SDA, I2C-1.3, I2C-2.3, I2C-3.3, I2C-4.3, I2C-5.3, IC2.4 (SDA), R3.1, SDA.1
TX: 1.1, ARD.1 (TX/1), UART.4
VBAT: BAT1.+ (VBAT), IC2.8 (VBAT)
VIN: ARD.VIN, VIN.1

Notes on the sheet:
Released under the Creative Commons Attribution Share-Alike License. http://creativecommons.org/licenses/by-sa/4.0/ Designed by Stephan Watterott (Watterott electronic)
(EthShield uses 2, 4, 10_SS)
Card inserted: CD shorted to GND
No Card: CD open
RV-8523 Real-Time-Clock
CR1225 Battery

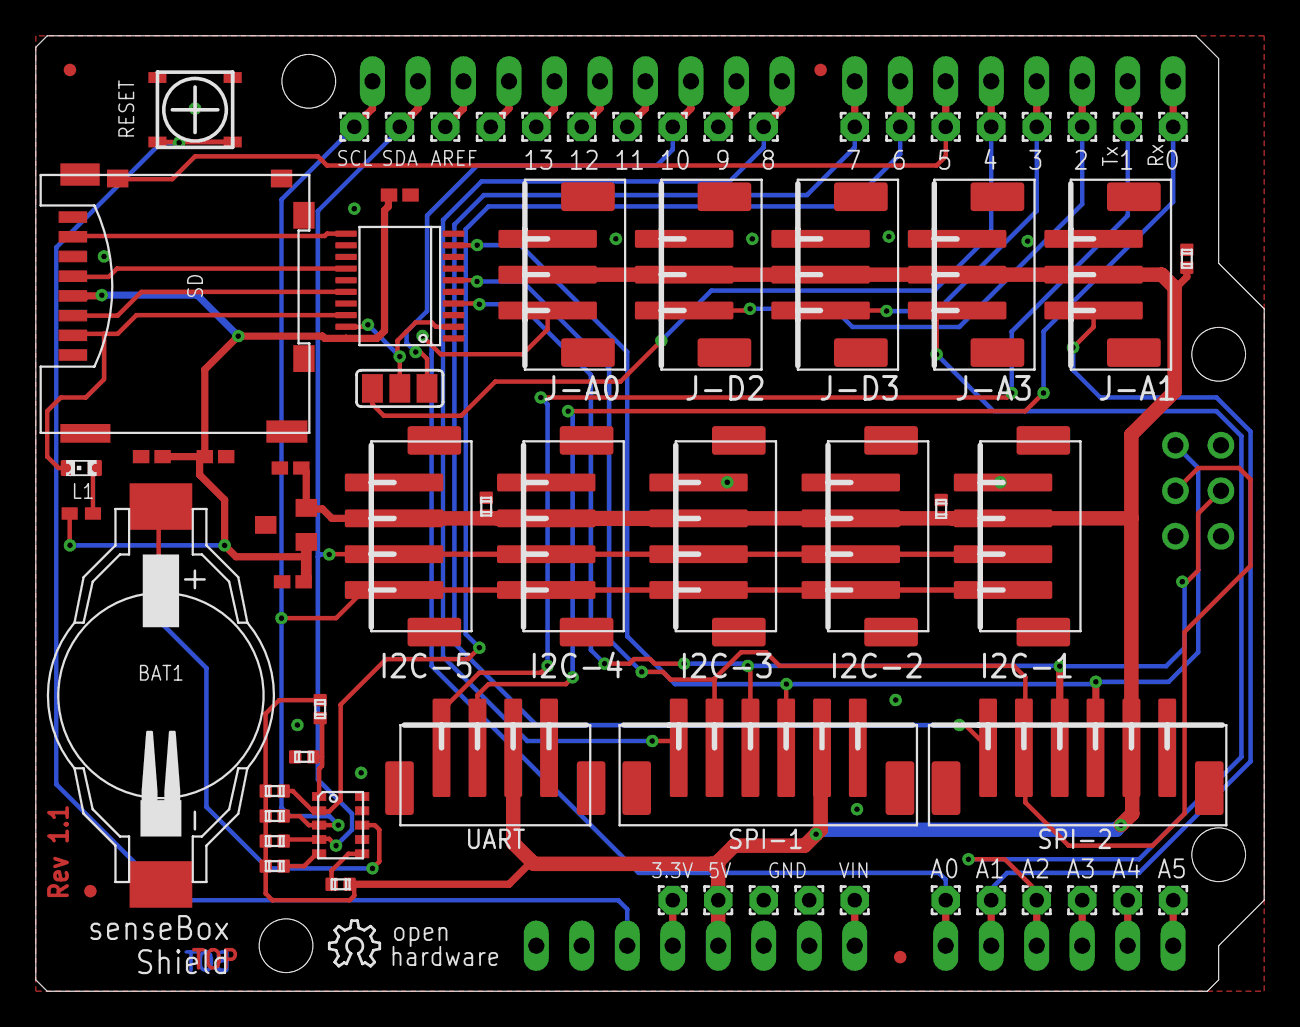
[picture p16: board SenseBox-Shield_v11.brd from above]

Board: 2 copper layers, 68.6 x 53.3 mm, 72 parts (0 on the bottom side), 42 nets.

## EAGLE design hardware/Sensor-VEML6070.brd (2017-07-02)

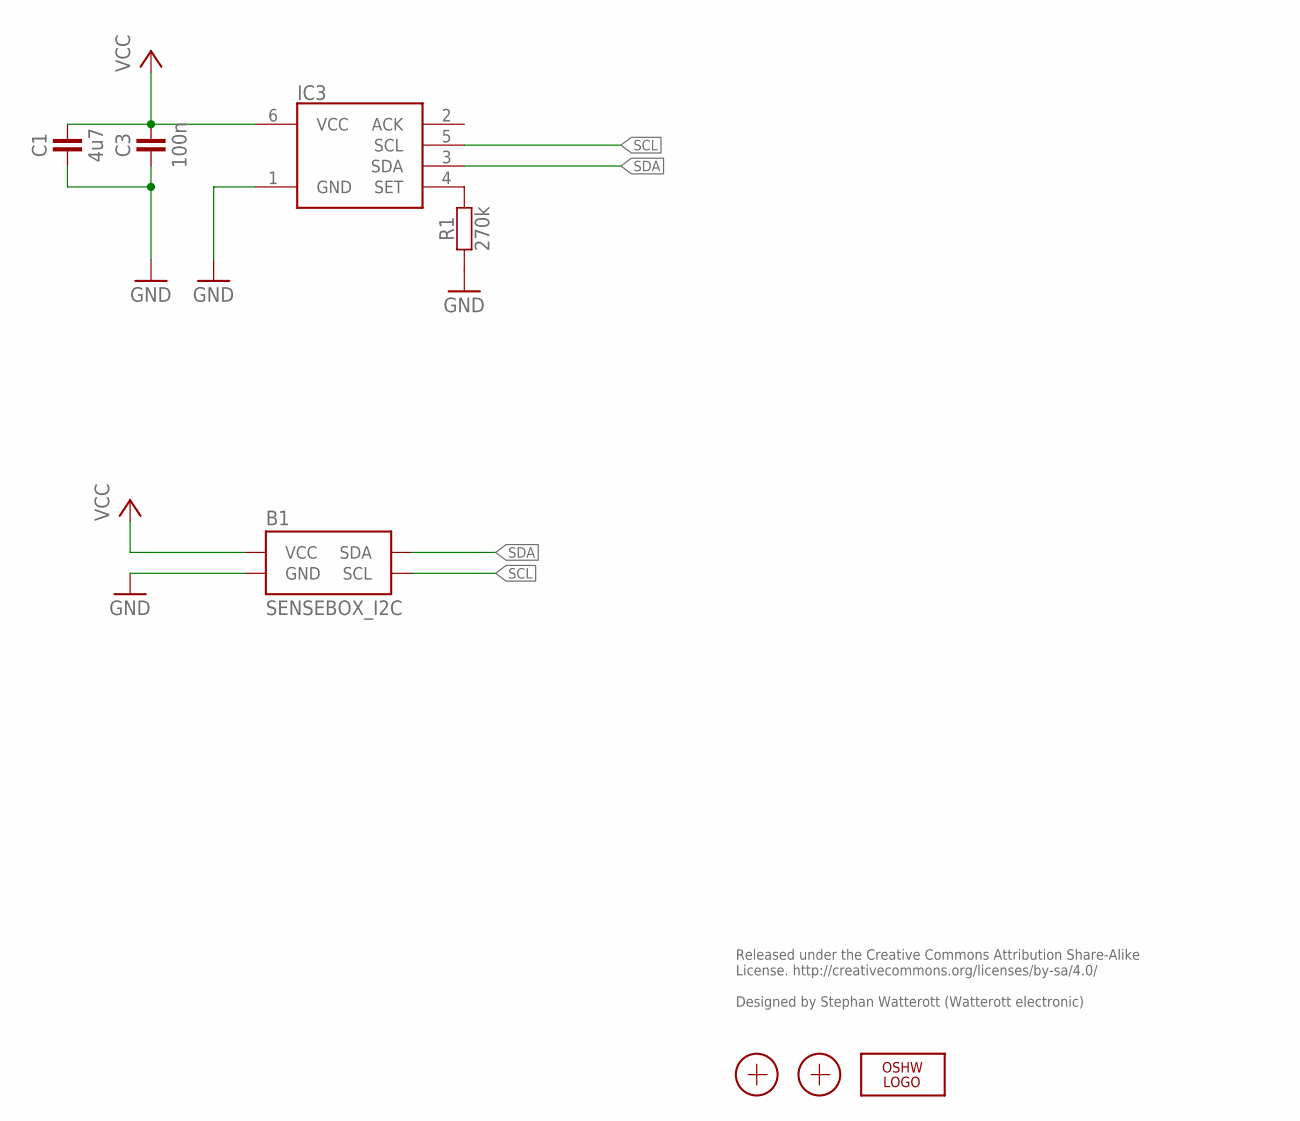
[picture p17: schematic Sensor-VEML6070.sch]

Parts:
B1: SENSEBOX_I2C; BREAKOUT_SENSEBOX_I2C
C1: 4u7; R0402
C3: 100n; R0402
IC3: VEML6070; OPLGA
LOGO2: OSHW_LOGOX0070; OSHW_6X70
R1: 270k; R0402
X1, X2: PASSER-07; PASSER_07MM

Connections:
GND: B1.GND, C1.1, C3.1, IC3.1 (GND), R1.1
unnamed: IC3.4 (SET), R1.2
SCL: B1.SCL, IC3.5 (SCL)
SDA: B1.SDA, IC3.3 (SDA)
VCC: B1.VCC, C1.2, C3.2, IC3.6 (VCC)

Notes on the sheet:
Released under the Creative Commons Attribution Share-Alike License. http://creativecommons.org/licenses/by-sa/4.0/ Designed by Stephan Watterott (Watterott electronic)

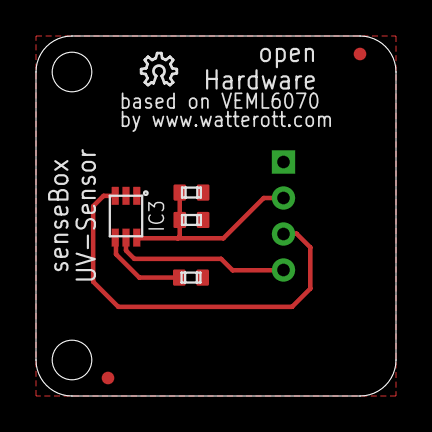
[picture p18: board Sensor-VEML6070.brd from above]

Board: 2 copper layers, 20.0 x 20.0 mm, 8 parts (0 on the bottom side), 5 nets.

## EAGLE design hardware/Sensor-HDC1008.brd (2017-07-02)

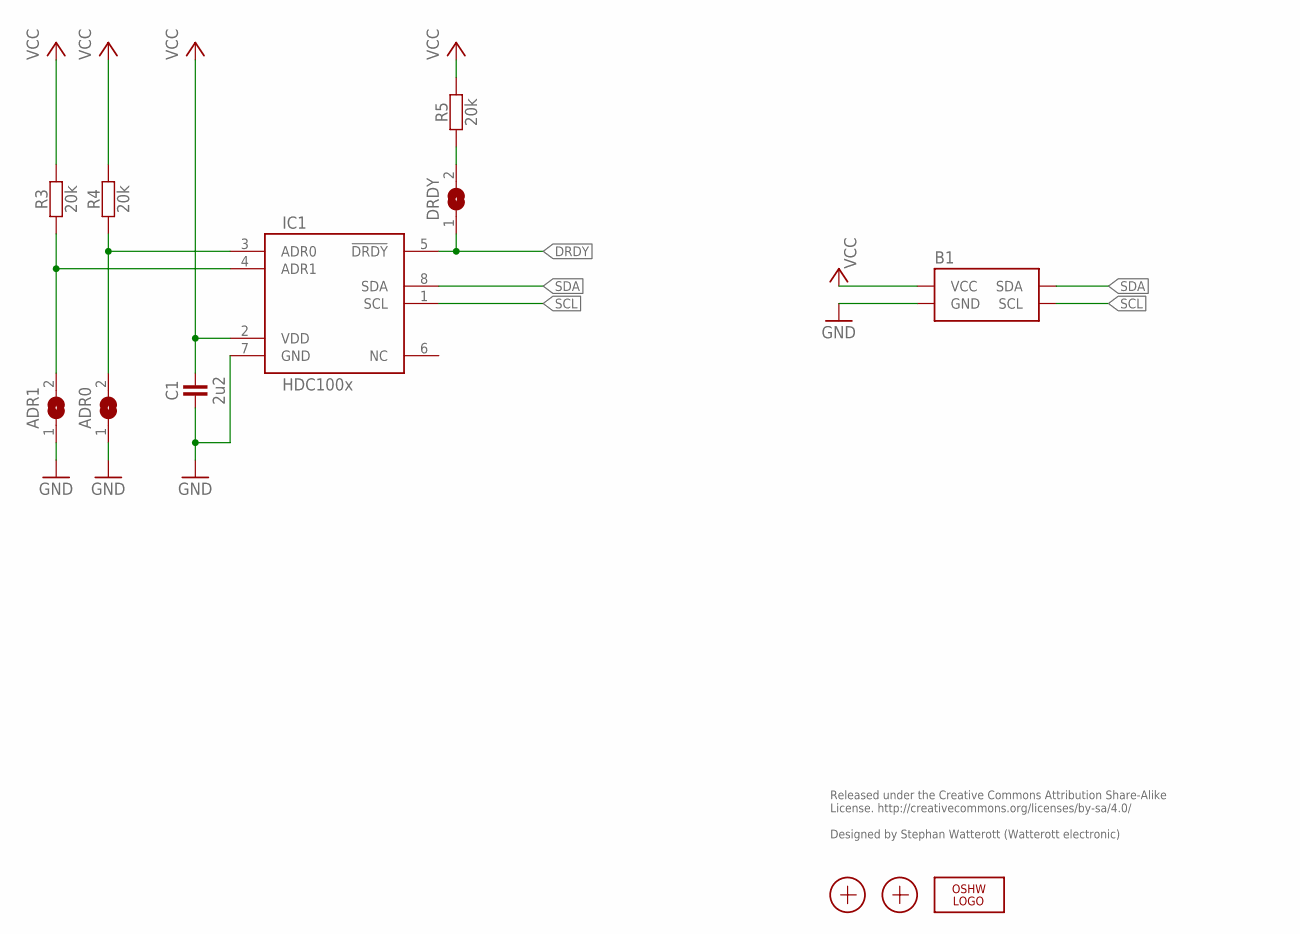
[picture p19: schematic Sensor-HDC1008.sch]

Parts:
ADR0, ADR1: JUMPER2-0402
B1: SENSEBOX_I2C
C1: 2u2; R0402
DRDY: JUMPER2-0402
IC1: HDC100x; WLCSP
LOGO2: OSHW_LOGOX0070; OSHW_6X70
R3, R4, R5: 20k; R0402
X1, X2: PASSER-07; PASSER_07MM

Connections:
ADR0: ADR0.2, IC1.3 (ADR0), R4.1
ADR1: ADR1.2, IC1.4 (ADR1), R3.1
DRDY: DRDY.1, IC1.5 (!DRDY)
GND: ADR0.1, ADR1.1, B1.GND, C1.1, IC1.7 (GND)
unnamed: DRDY.2, R5.1
SCL: B1.SCL, IC1.1 (SCL)
SDA: B1.SDA, IC1.8 (SDA)
VCC: B1.VCC, C1.2, IC1.2 (VDD), R3.2, R4.2, R5.2

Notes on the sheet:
Released under the Creative Commons Attribution Share-Alike License. http://creativecommons.org/licenses/by-sa/4.0/ Designed by Stephan Watterott (Watterott electronic)

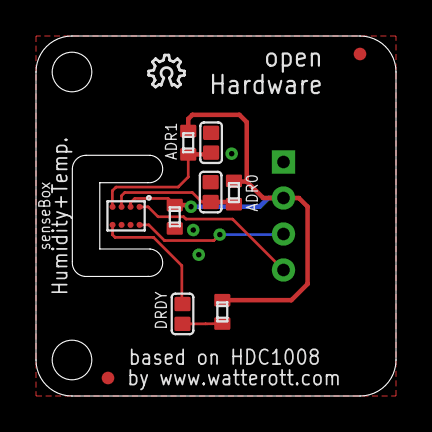
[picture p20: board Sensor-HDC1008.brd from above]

Board: 2 copper layers, 20.0 x 20.0 mm, 12 parts (0 on the bottom side), 8 nets.
